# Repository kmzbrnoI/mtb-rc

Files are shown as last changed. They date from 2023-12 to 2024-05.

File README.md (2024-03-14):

MTB-RC – MTBbus RailCom detector
================================

MTB-RC is a RailCom detector sending addresses of a detected mobile decoders
via MTBbus.

## Features

* 8 track sections.
* [MTBbus v4](https://mtb.kmz-brno.cz/) interface.
* Reading DCC addresses of mobile decoders.
* Galvanic separation of MTB & DCC.
* Single STM32F103 main MCU.
* MTB part power input: 8-20 V.
* DCC part powered directly from DCC.
* Several IO & power protections (ESD, overvoltage, switched polarity, ...).
* 4->1 track time multiplexing.
* Opensource & openhardware design.

## PCB

See [README in `pcb` subfolder](pcb/README.md).

## Firmware

See [README in `fw` subfolder](fw/README.md).

## Authors

* Kateřina Hanáková
* [Jan Horáček](mailto:jan.horacek@kmz-brno.cz)

## Licence

See README in subfolders for licenses regarding pcb design and firmware.

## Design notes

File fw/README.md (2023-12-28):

MTB-RC Firmware
===============

This repository contains firmware for main MCU STM32F103 of MTB-RC module written
in C99.

## Compiling

Requirements:
* `arm-none-eabi-gcc`
* STM32CubeF1 MCU Firmware Package v1.8.5
  - Download package
  - Set `STM32_CUBE_PATH_185` environment variable to the location of downloaded package
  - See `Makefile`
* `make`

Howto compile:

```bash
$ make
```

## Flashing

Requirements:
* `st-flash` (via STlink)

MTB-RC module contains programming connector. Use STlink to program the MCU.
```bash
$ make flash_stlink
```

## Debugging

Requirements:
* `openocd`
* `arm-none-eabi-gdb`

Howto debug:

```bash
$ openocd
$ arm-none-eabi-gdb build/mtb-rc.elf
(gdb) target extended-remote :3333
(gdb) b main
```

## License

This application is released under the [Apache License v2.0
](https://www.apache.org/licenses/LICENSE-2.0).

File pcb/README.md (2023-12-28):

MTB-RC PCB
==========

## Design

Schematics & PCB are designed in KiCad 7.

## Production

PCB is prepared to be automatically assembled in [JLCPCB](https://jlcpcb.com/).
SMD parts on **bottom** side should be assembled. Each SMD part has its `LCSC_ITEM`
attribute set.

```bash
$ make fab
```

## License

Content of this directory is provided under [Creative Commons
Attribution-ShareAlike 4.0
License](https://creativecommons.org/licenses/by-sa/4.0/) as openhardware
project. You may download any data, contribute to the project, create PCB
yourself or even sell it yourself.

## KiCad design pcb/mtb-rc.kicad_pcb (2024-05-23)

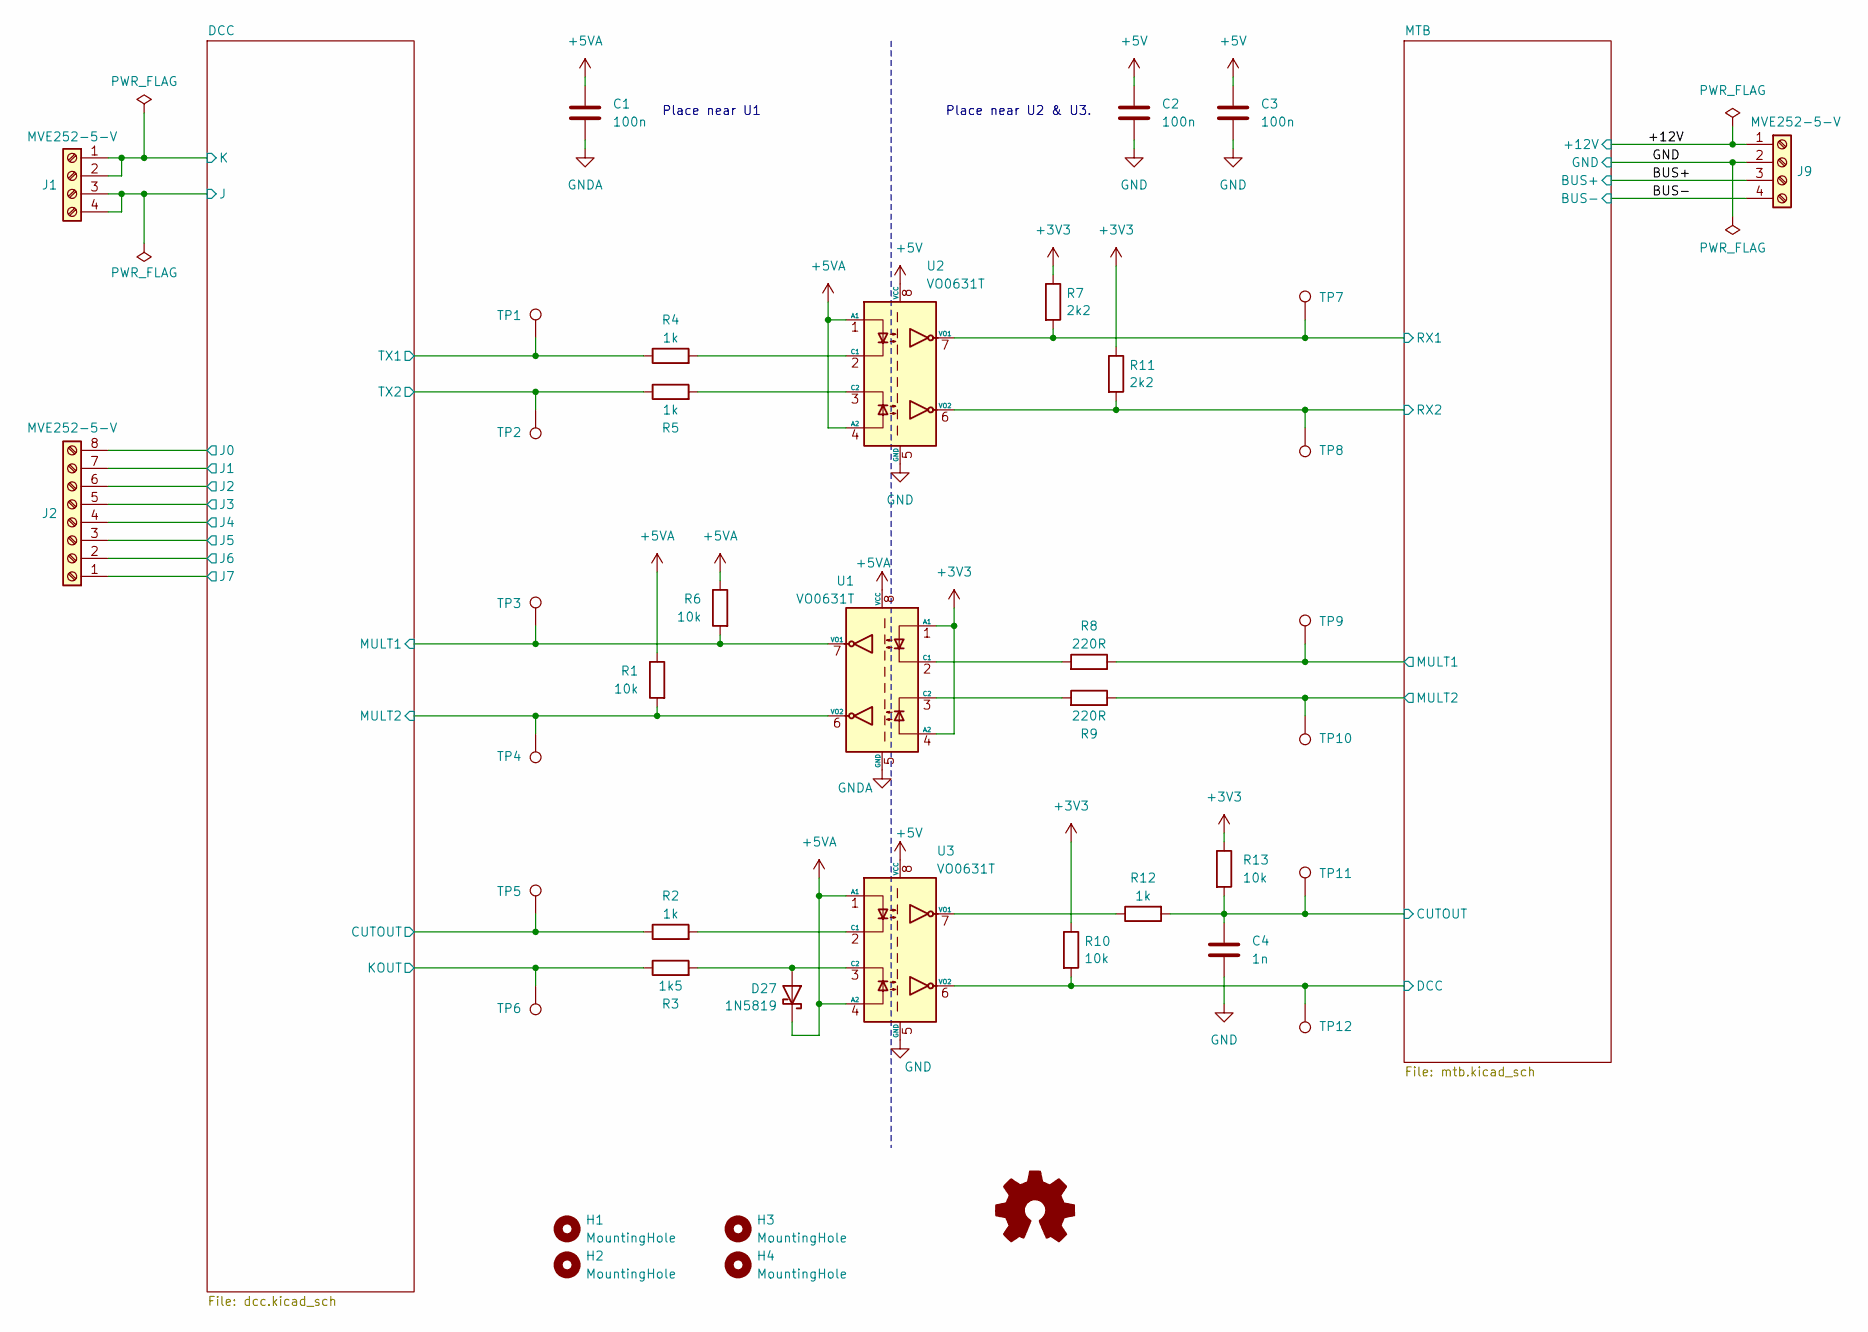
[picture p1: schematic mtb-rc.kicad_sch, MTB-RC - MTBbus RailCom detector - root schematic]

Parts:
C1, C2, C3: 100n; C_0805_2012Metric_Pad1.18x1.45mm_HandSolder
C4: 1n; C_0805_2012Metric_Pad1.18x1.45mm_HandSolder
D27: 1N5819; D_SOD-123
H1, H2, H3, H4: MountingHole; MountingHole_3.2mm_M3_Pad_Via
J1, J9: MVE252-5-V; MVE252-5-V-2x
J2: MVE252-5-V; MVE252-5-V-4x
R1, R6, R10, R13: 10k; R_0805_2012Metric_Pad1.20x1.40mm_HandSolder
R2, R4, R5, R12: 1k; R_0805_2012Metric_Pad1.20x1.40mm_HandSolder
R3: 1k5; R_0805_2012Metric_Pad1.20x1.40mm_HandSolder
R7, R11: 2k2; R_0805_2012Metric_Pad1.20x1.40mm_HandSolder
R8, R9: 220R; R_0805_2012Metric_Pad1.20x1.40mm_HandSolder
TP1, TP2, TP3, TP4, TP5, TP6, TP7, TP8, TP9, TP10, TP11, TP12: PinHeader_1x01_P2.54mm_Vertical
U1, U2, U3: VO0631T; SOIC-8_3.9x4.9mm_P1.27mm

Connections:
+3V3: R7.1, R10.1, R11.1, R13.1, U1.1 (A1), U1.4 (A2); also elsewhere on the board
+5V: C2.1, C3.1, U2.8 (VCC), U3.8 (VCC); also elsewhere on the board
+5VA: C1.1, D27.1 (K), R1.1, R6.1, U1.8 (VCC), U2.1 (A1), U2.4 (A2), U3.1 (A1), U3.4 (A2); also elsewhere on the board
/+12V: J9.1; also elsewhere on the board
/BUS+: J9.3; also elsewhere on the board
/BUS-: J9.4; also elsewhere on the board
/DCC/CUTOUT: R2.1, TP5.1; also elsewhere on the board
/DCC/J: J1.3, J1.4; also elsewhere on the board
/DCC/J0: J2.8; also elsewhere on the board
/DCC/J1: J2.7; also elsewhere on the board
/DCC/J2: J2.6; also elsewhere on the board
/DCC/J3: J2.5; also elsewhere on the board
/DCC/J4: J2.4; also elsewhere on the board
/DCC/J5: J2.3; also elsewhere on the board
/DCC/J6: J2.2; also elsewhere on the board
/DCC/J7: J2.1; also elsewhere on the board
/DCC/MULT1: R6.2, TP3.1, U1.7 (VO1); also elsewhere on the board
/DCC/MULT2: R1.2, TP4.1, U1.6 (VO2); also elsewhere on the board
/DCC/TX1: R4.1, TP1.1; also elsewhere on the board
/DCC/TX2: R5.1, TP2.1; also elsewhere on the board
/MTB/CUTOUT: C4.1, R12.2, R13.2, TP11.1; also elsewhere on the board
/MTB/DCC: R10.2, TP12.1, U3.6 (VO2); also elsewhere on the board
/MTB/MULT1: R8.1, TP9.1; also elsewhere on the board
/MTB/MULT2: R9.1, TP10.1; also elsewhere on the board
/MTB/RX1: R7.2, TP7.1, U2.7 (VO1); also elsewhere on the board
/MTB/RX2: R11.2, TP8.1, U2.6 (VO2); also elsewhere on the board
GND: C2.2, C3.2, C4.2, J9.2, U2.5 (GND), U3.5 (GND); also elsewhere on the board
GNDA: C1.2, U1.5 (GND); also elsewhere on the board
K: J1.1, J1.2; also elsewhere on the board
KOUT: R3.1, TP6.1; also elsewhere on the board
unnamed: D27.2 (A), R3.2, U3.3 (C2)
unnamed: R8.2, U1.2 (C1)
unnamed: R9.2, U1.3 (C2)
unnamed: R4.2, U2.2 (C1)
unnamed: R5.2, U2.3 (C2)
unnamed: R2.2, U3.2 (C1)
unnamed: R12.1, U3.7 (VO1)

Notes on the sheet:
Place near U2 & U3.
Place near U1

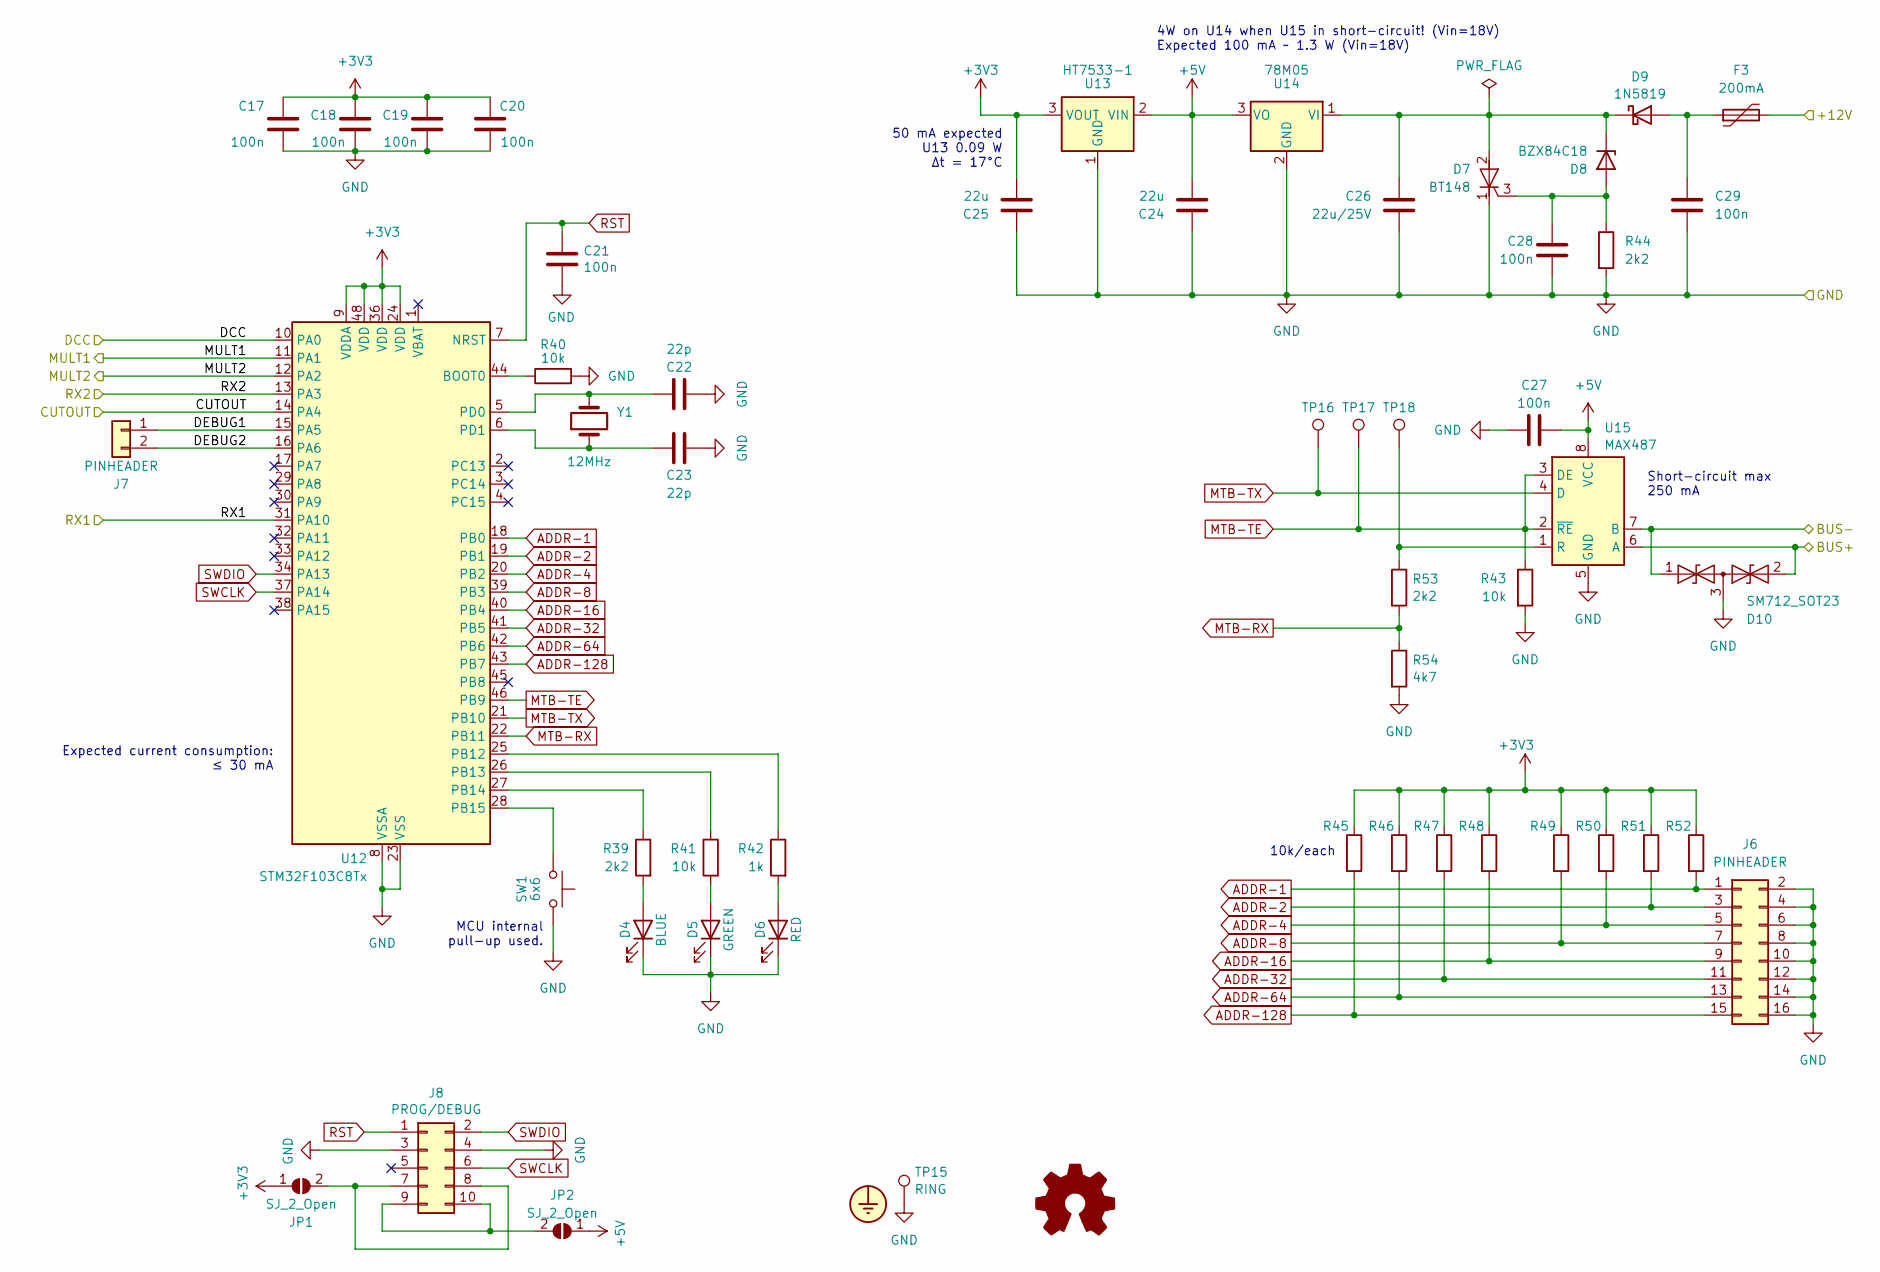
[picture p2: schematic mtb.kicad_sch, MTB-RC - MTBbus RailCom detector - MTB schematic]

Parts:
C17, C18, C19, C20, C27: 100n; C_0805_2012Metric_Pad1.18x1.45mm_HandSolder
C21: 100n; C_0805_2012Metric_Pad1.18x1.45mm_HandSolder; LCSC C49678
C22, C23: 22p; C_0805_2012Metric_Pad1.18x1.45mm_HandSolder
C24, C25: 22u; C_0805_2012Metric_Pad1.18x1.45mm_HandSolder
C26: 22u/25V; C_0805_2012Metric_Pad1.18x1.45mm_HandSolder
C28, C29: 100n; C_0805_2012Metric
D4: BLUE; LED_0805_2012Metric_Pad1.15x1.40mm_HandSolder
D5: GREEN; LED_0805_2012Metric_Pad1.15x1.40mm_HandSolder
D6: RED; LED_0805_2012Metric_Pad1.15x1.40mm_HandSolder
D7: BT148; SOT-223
D8: BZX84C18; SOT-23
D9: 1N5819; D_SOD-123
D10: SM712_SOT23; SOT-23
F3: 200mA; Fuse_1812_4532Metric_Pad1.30x3.40mm_HandSolder
J6: PINHEADER; PinHeader_2x08_P2.54mm_Vertical
J7: PINHEADER; PinHeader_1x02_P2.54mm_Vertical
J8: PROG/DEBUG; PinHeader_2x05_P2.54mm_Vertical; JLCPCB_IGNORE true
JP1, JP2: SJ_2_Open; PinHeader_1x02_P2.54mm_Vertical; JLCPCB_IGNORE true
R39, R44, R53: 2k2; R_0805_2012Metric_Pad1.20x1.40mm_HandSolder
R40, R41, R43, R45, R46, R47, R48, R49, R50, R51, R52: 10k; R_0805_2012Metric_Pad1.20x1.40mm_HandSolder
R42: 1k; R_0805_2012Metric_Pad1.20x1.40mm_HandSolder
R54: 4k7; R_0805_2012Metric_Pad1.20x1.40mm_HandSolder
SW1: 6x6; SW_PUSH_6mm_H4.3mm
TP15: RING; TestPoint_Loop_D1.80mm_Drill1.0mm_Beaded
TP16, TP17, TP18: PAD; PinHeader_1x01_P2.54mm_Vertical
U12: STM32F103C8Tx; LQFP-48_7x7mm_P0.5mm
U13: HT7533-1; SOT-89-3_Handsoldering
U14: 78M05; TO-252-2
U15: MAX487; DIP-8_W7.62mm_LongPads
Y1: 12MHz; Crystal_HC49-U_Vertical

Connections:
+3V3: C17.1, C18.1, C19.1, C20.1, C25.2, JP1.1 (A), R45.1, R46.1, R47.1, R48.1, R49.1, R50.1, R51.1, R52.1, U12.9 (VDDA), U12.24 (VDD), U12.36 (VDD), U12.48 (VDD), U13.3 (VOUT); also elsewhere on the board
+5V: C24.2, C27.1, JP2.1 (A), U13.2 (VIN), U14.3 (VO), U15.8 (VCC); also elsewhere on the board
/+12V: F3.2; also elsewhere on the board
/BUS+: D10.2 (A2), U15.6 (A); also elsewhere on the board
/BUS-: D10.1 (A1), U15.7 (B); also elsewhere on the board
/MTB/CUTOUT: U12.14 (PA4); also elsewhere on the board
/MTB/DCC: U12.10 (PA0); also elsewhere on the board
/MTB/DEBUG1: J7.1, U12.15 (PA5)
/MTB/DEBUG2: J7.2, U12.16 (PA6)
/MTB/MULT1: U12.11 (PA1); also elsewhere on the board
/MTB/MULT2: U12.12 (PA2); also elsewhere on the board
/MTB/RX1: U12.31 (PA10); also elsewhere on the board
/MTB/RX2: U12.13 (PA3); also elsewhere on the board
ADDR-1: J6.1, R52.2, U12.18 (PB0)
ADDR-2: J6.3, R51.2, U12.19 (PB1)
ADDR-4: J6.5, R50.2, U12.20 (PB2)
ADDR-8: J6.7, R49.2, U12.39 (PB3)
ADDR-16: J6.9, R48.2, U12.40 (PB4)
ADDR-32: J6.11, R47.2, U12.41 (PB5)
ADDR-64: J6.13, R46.2, U12.42 (PB6)
ADDR-128: J6.15, R45.2, U12.43 (PB7)
GND: C17.2, C18.2, C19.2, C20.2, C21.1, C22.2, C23.2, C24.1, C25.1, C26.2, C27.2, C28.2, C29.2, D4.1 (K), D5.1 (K), D6.1 (K), D7.1 (K), D10.3 (common), J6.2, J6.4, J6.6, J6.8, J6.10, J6.12, J6.14, J6.16, J8.3, J8.4, R40.2, R43.2, R44.2, R54.2, SW1.1, TP15.1, U12.8 (VSSA), U12.23 (VSS), U12.35 (VSS), U12.47 (VSS), U13.1 (GND), U14.2 (GND), U15.5 (GND); also elsewhere on the board
MTB-RX: R53.2, R54.1, U12.22 (PB11)
MTB-TE: R43.1, TP17.1, U12.46 (PB9), U15.2 (~RE), U15.3 (DE)
MTB-TX: TP16.1, U12.21 (PB10), U15.4 (D)
unnamed: D4.2 (A), R39.2
unnamed: D5.2 (A), R41.2
unnamed: D6.2 (A), R42.2
unnamed: C26.1, D7.2 (A), D8.3 (K), D9.1 (K), U14.1 (VI)
unnamed: C28.1, D7.3 (G), D8.1 (A), R44.1
unnamed: C29.1, D9.2 (A), F3.1
unnamed: J8.7, J8.8, JP1.2 (B)
unnamed: J8.9, J8.10, JP2.2 (B)
unnamed: R40.1, U12.44 (BOOT0)
unnamed: R42.1, U12.25 (PB12)
unnamed: R41.1, U12.26 (PB13)
unnamed: R39.1, U12.27 (PB14)
unnamed: SW1.2, U12.28 (PB15)
unnamed: C22.1, U12.5 (PD0), Y1.2
unnamed: C23.1, U12.6 (PD1), Y1.1
unnamed: R53.1, TP18.1, U15.1 (R)
RST: C21.2, J8.1, U12.7 (NRST)
SWCLK: J8.6, U12.37 (PA14)
SWDIO: J8.2, U12.34 (PA13)

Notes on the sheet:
4W on U14 when U15 in short-circuit! (Vin=18V) Expected 100 mA ~ 1.3 W (Vin=18V)
Expected current consumption: ≤ 30 mA
50 mA expected U13 0.09 W Δt = 17°C
10k/each
Short-circuit max 250 mA
MCU internal pull-up used.

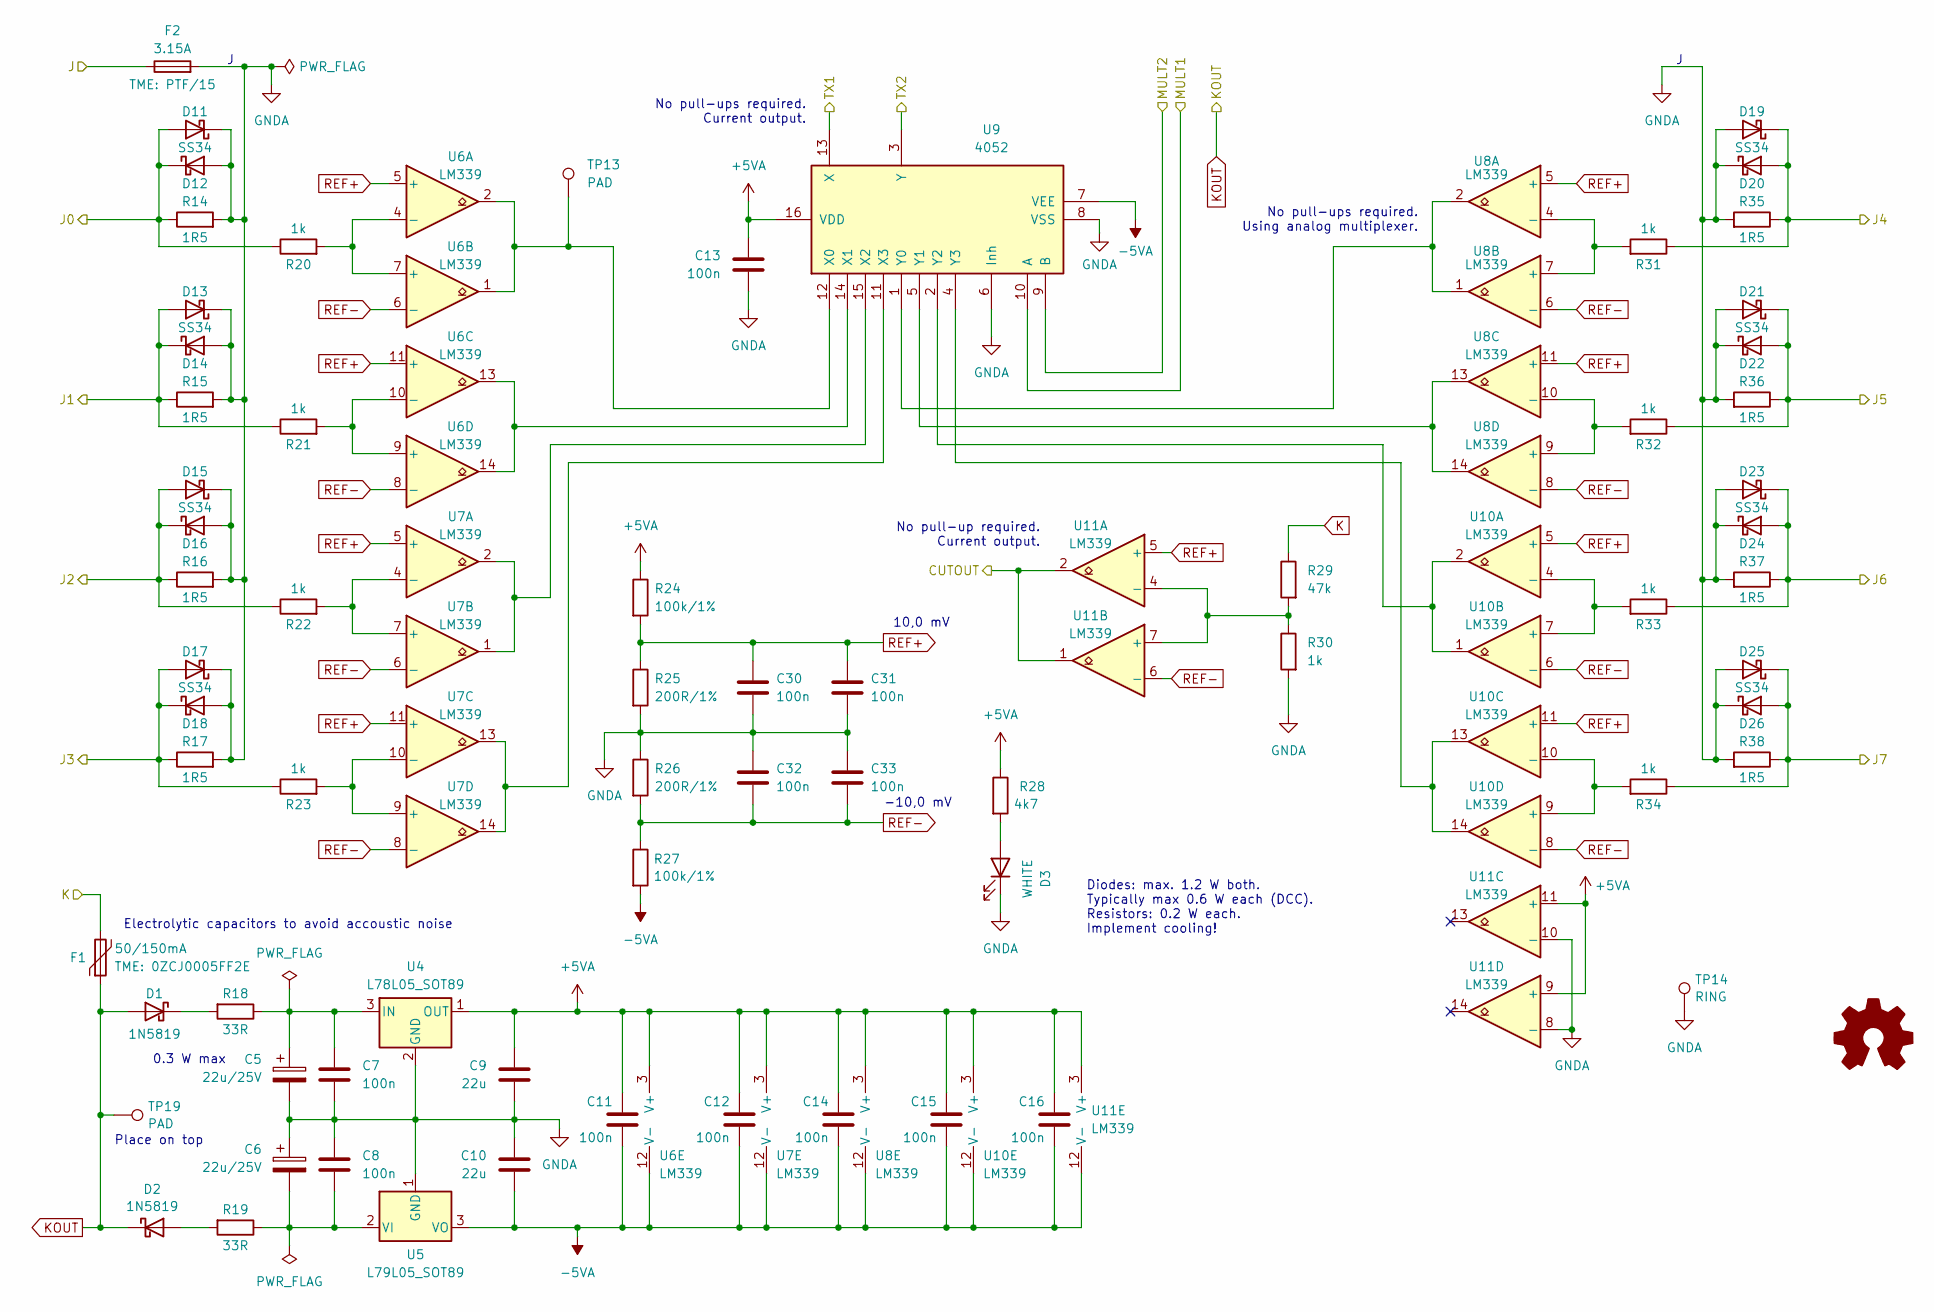
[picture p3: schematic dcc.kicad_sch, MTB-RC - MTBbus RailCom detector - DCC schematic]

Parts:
C5, C6: 22u/25V; CP_Radial_D5.0mm_P2.00mm
C7, C8, C30, C32: 100n; C_0805_2012Metric_Pad1.18x1.45mm_HandSolder
C9, C10: 22u; C_0805_2012Metric_Pad1.18x1.45mm_HandSolder
C11, C12, C13, C14, C15, C16, C31, C33: 100n; C_0805_2012Metric
D1, D2: 1N5819; D_SOD-123
D3: WHITE; LED_0805_2012Metric_Pad1.15x1.40mm_HandSolder
D11, D12, D13, D14, D15, D16, D17, D18, D19, D20, D21, D22, D23, D24, D25, D26: SS34; D_SMA_Handsoldering
F1: 50/150mA; Fuse_1206_3216Metric_Pad1.42x1.75mm_HandSolder
F2: 3.15A; Fuseholder_Cylinder-5x20mm_Stelvio-Kontek_PTF78_Horizontal_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
R14, R15, R16, R17, R35, R36, R37, R38: 1R5; R_2512_6332Metric_Pad1.40x3.35mm_HandSolder
R18, R19: 33R; R_2512_6332Metric_Pad1.40x3.35mm_HandSolder
R20, R21, R22, R23, R30, R31, R32, R33, R34: 1k; R_0805_2012Metric
R24, R27: 100k/1%; R_0805_2012Metric_Pad1.20x1.40mm_HandSolder
R25, R26: 200R/1%; R_0805_2012Metric_Pad1.20x1.40mm_HandSolder
R28: 4k7; R_0805_2012Metric_Pad1.20x1.40mm_HandSolder
R29: 47k; R_0805_2012Metric
TP13, TP19: PAD; TestPoint_Pad_D2.0mm
TP14: RING; TestPoint_Loop_D1.80mm_Drill1.0mm_Beaded
U4: L78L05_SOT89; SOT-89-3
U5: L79L05_SOT89; SOT-89-3
U6, U7, U8, U10, U11: LM339; SO-14_3.9x8.65mm_P1.27mm
U9: 4052; SO-16_3.9x9.9mm_P1.27mm

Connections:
+5VA: C9.1, C11.1, C12.1, C13.1, C14.1, C15.1, C16.1, R24.1, R28.1, U4.1 (OUT), U6.3 (V+), U7.3 (V+), U8.3 (V+), U9.16 (VDD), U10.3 (V+), U11.3 (V+), U11.9 (+), U11.11 (+); also elsewhere on the board
-5VA: C10.2, C11.2, C12.2, C14.2, C15.2, C16.2, R27.2, U5.3 (VO), U6.12 (V-), U7.12 (V-), U8.12 (V-), U9.7 (VEE), U10.12 (V-), U11.12 (V-)
/DCC/CUTOUT: U11.1, U11.2; also elsewhere on the board
/DCC/J: F2.1; also elsewhere on the board
/DCC/J0: D11.2 (A), D12.1 (K), R14.1, R20.1; also elsewhere on the board
/DCC/J1: D13.2 (A), D14.1 (K), R15.1, R21.1; also elsewhere on the board
/DCC/J2: D15.2 (A), D16.1 (K), R16.1, R22.1; also elsewhere on the board
/DCC/J3: D17.2 (A), D18.1 (K), R17.1, R23.1; also elsewhere on the board
/DCC/J4: D19.1 (K), D20.2 (A), R31.1, R35.1; also elsewhere on the board
/DCC/J5: D21.1 (K), D22.2 (A), R32.1, R36.1; also elsewhere on the board
/DCC/J6: D23.1 (K), D24.2 (A), R33.1, R37.1; also elsewhere on the board
/DCC/J7: D25.1 (K), D26.2 (A), R34.1, R38.1; also elsewhere on the board
/DCC/MULT1: U9.10 (A); also elsewhere on the board
/DCC/MULT2: U9.9 (B); also elsewhere on the board
/DCC/TX1: U9.13 (X); also elsewhere on the board
/DCC/TX2: U9.3 (Y); also elsewhere on the board
GNDA: C5.2, C6.1, C7.2, C8.1, C9.2, C10.1, C13.2, C30.2, C31.2, C32.1, C33.1, D3.1 (K), D11.1 (K), D12.2 (A), D13.1 (K), D14.2 (A), D15.1 (K), D16.2 (A), D17.1 (K), D18.2 (A), D19.2 (A), D20.1 (K), D21.2 (A), D22.1 (K), D23.2 (A), D24.1 (K), D25.2 (A), D26.1 (K), F2.2, R14.2, R15.2, R16.2, R17.2, R25.2, R26.1, R30.2, R35.2, R36.2, R37.2, R38.2, TP14.1, U4.2 (GND), U5.1 (GND), U9.6 (Inh), U9.8 (VSS), U11.8 (-), U11.10 (-); also elsewhere on the board
K: F1.2, R29.1; also elsewhere on the board
KOUT: D1.2 (A), D2.1 (K), F1.1, TP19.1; also elsewhere on the board
unnamed: D1.1 (K), R18.2
unnamed: D2.2 (A), R19.2
unnamed: D3.2 (A), R28.2
unnamed: C5.1, C7.1, R18.1, U4.3 (IN)
unnamed: C6.2, C8.2, R19.1, U5.2 (VI)
unnamed: R20.2, U6.4 (-), U6.7 (+)
unnamed: R21.2, U6.9 (+), U6.10 (-)
unnamed: R22.2, U7.4 (-), U7.7 (+)
unnamed: R23.2, U7.9 (+), U7.10 (-)
unnamed: R31.2, U8.4 (-), U8.7 (+)
unnamed: R32.2, U8.9 (+), U8.10 (-)
unnamed: TP13.1, U6.1, U6.2, U9.12 (X0)
unnamed: U6.13, U6.14, U9.14 (X1)
unnamed: U7.1, U7.2, U9.15 (X2)
unnamed: U7.13, U7.14, U9.11 (X3)
unnamed: U8.1, U8.2, U9.1 (Y0)
unnamed: U8.13, U8.14, U9.5 (Y1)
unnamed: U9.2 (Y2), U10.1, U10.2
unnamed: U9.4 (Y3), U10.13, U10.14
unnamed: R33.2, U10.4 (-), U10.7 (+)
unnamed: R34.2, U10.9 (+), U10.10 (-)
unnamed: R29.2, R30.1, U11.4 (-), U11.7 (+)
REF+: C30.1, C31.1, R24.2, R25.1, U6.5 (+), U6.11 (+), U7.5 (+), U7.11 (+), U8.5 (+), U8.11 (+), U10.5 (+), U10.11 (+), U11.5 (+)
REF-: C32.2, C33.2, R26.2, R27.1, U6.6 (-), U6.8 (-), U7.6 (-), U7.8 (-), U8.6 (-), U8.8 (-), U10.6 (-), U10.8 (-), U11.6 (-)

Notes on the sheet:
10,0 mV
No pull-ups required. Current output.
Diodes: max. 1.2 W both. Typically max 0.6 W each (DCC). Resistors: 0.2 W each. Implement cooling!
No pull-ups required. Using analog multiplexer.
Place on top
Electrolytic capacitors to avoid accoustic noise
0.3 W max
No pull-up required. Current output.
-10,0 mV

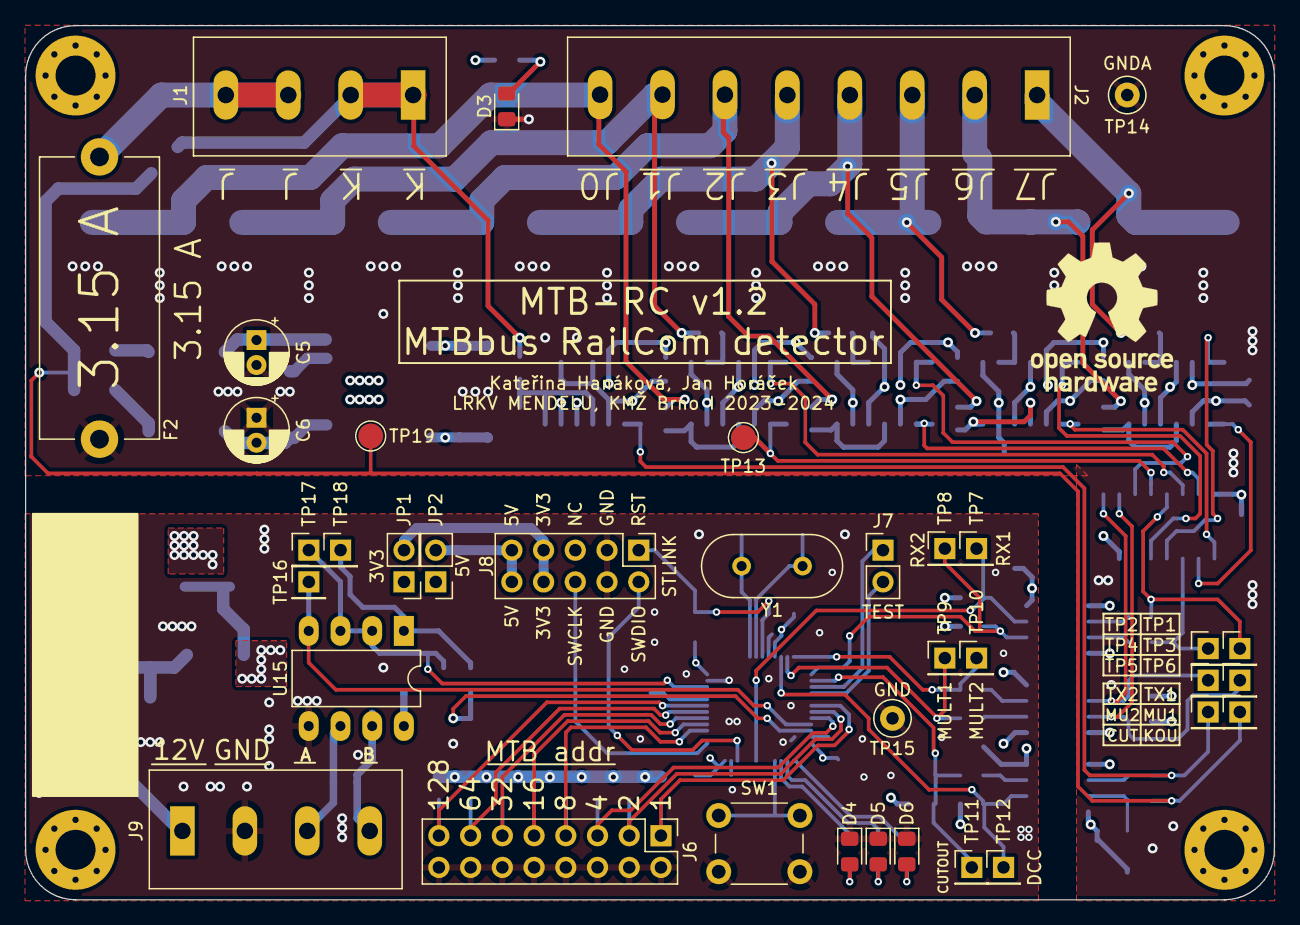
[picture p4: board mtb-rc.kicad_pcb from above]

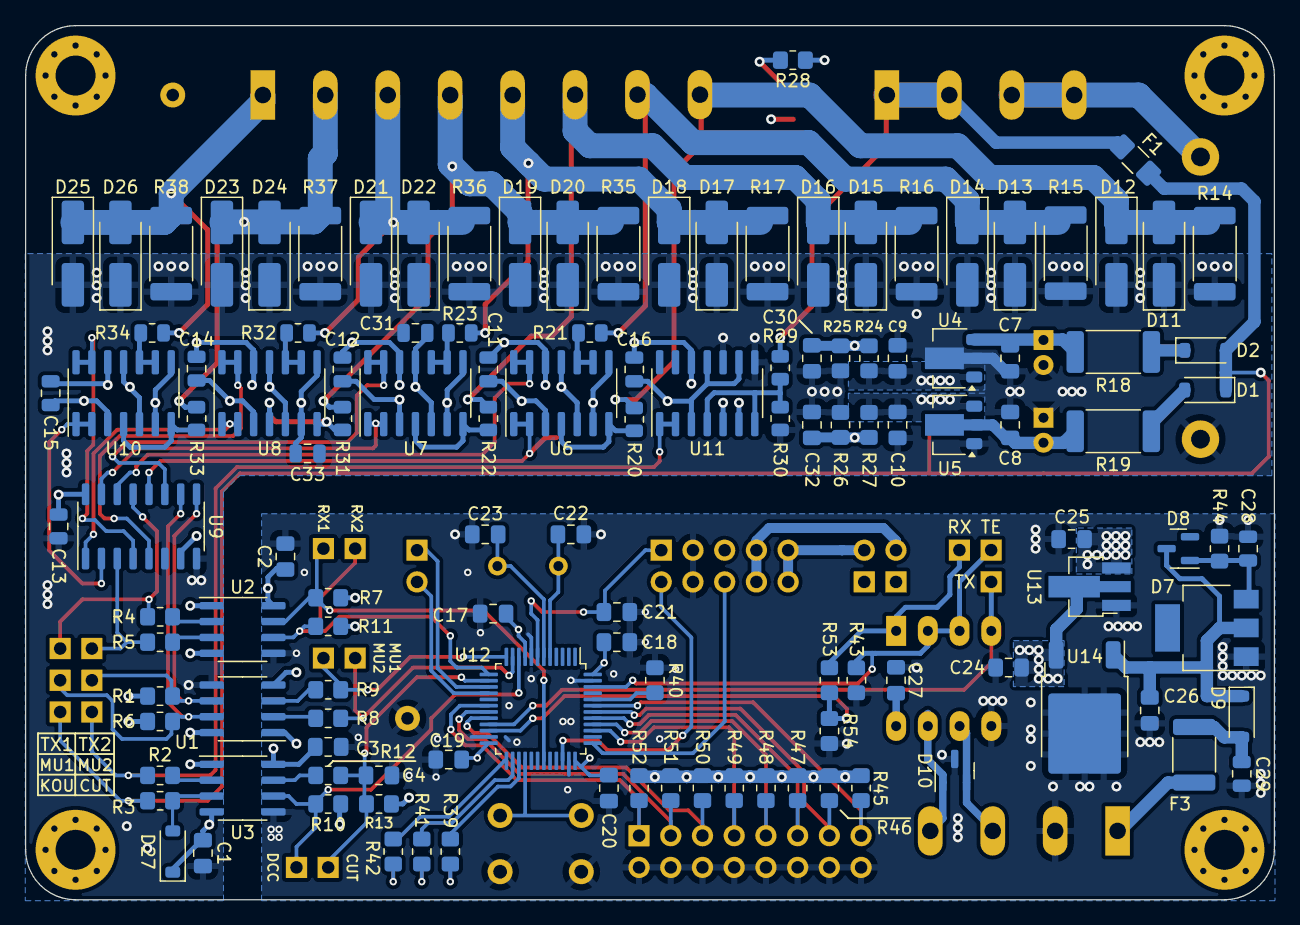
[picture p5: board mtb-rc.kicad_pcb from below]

Board: 4 copper layers, 100.0 x 70.0 mm, 165 parts (124 on the bottom side), 94 nets.

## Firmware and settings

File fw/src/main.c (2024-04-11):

#include <stdbool.h>
#include <string.h>
#include "dwt_delay.h"
#include "assert.h"
#include "main.h"
#include "gpio.h"
#include "mtbbus.h"
#include "railcom_ll.h"
#include "railcom_mw.h"
#include "railcom_addrs.h"
#include "config.h"
#include "diag.h"
#include "inputs.h"
#include "dcc_ll.h"
#include "dcc_mw.h"
#include "common.h"

/* Private variables ---------------------------------------------------------*/

TIM_HandleTypeDef htim3; // general-purpose @ 500 us

#define LED_GR_ON 5
#define LED_GR_OFF 2
uint8_t led_gr_counter = 0;

#define LED_RED_OK_ON 40
#define LED_RED_OK_OFF 20
#define LED_RED_ERR_ON 100
#define LED_RED_ERR_OFF 50
uint8_t led_red_counter = 0;

bool beacon = false;

#define LED_BLUE_BEACON_ON 100
#define LED_BLUE_BEACON_OFF 50
uint8_t led_blue_counter = 0;

volatile bool btn_debounce_to_update = false;

#define MTBBUS_TIMEOUT_MAX 100 // 1 s
volatile uint8_t mtbbus_timeout = MTBBUS_TIMEOUT_MAX; // increment each 10 ms

#define BTN_PRESS_1S 100
volatile uint8_t btn_press_time = 0;

volatile bool mtbbus_auto_speed_in_progress = false;
volatile uint8_t mtbbus_auto_speed_timer = 0;
volatile MtbBusSpeed mtbbus_auto_speed_last;
#define MTBBUS_AUTO_SPEED_TIMEOUT 20 // 200 ms

volatile bool elapsed_10ms = false;
volatile bool elapsed_100ms = false;

/* Private function prototypes -----------------------------------------------*/

static void init(void);
static void init_clock(void);
static void init_tim3(void);
static void timer_10ms(void);

void mtbbus_received(bool broadcast, uint8_t command_code, uint8_t *data, uint8_t data_len); // intentionally not static
static void mtbbus_send_ack(void);
static void mtbbus_send_inputs(uint8_t message_code);
static void mtbbus_send_error(uint8_t code);
static void mtbbus_update_polarity(void);
static inline bool mtbbus_addressed(void);
static void mtbbus_send_diag_value(uint8_t i);

static void autodetect_mtbbus_speed(void);
static void autodetect_mtbbus_speed_stop(void);
static void mtbbus_auto_speed_next(void);
static void mtbbus_auto_speed_received(void);

static void leds_update(void);
static void led_red_ok(void);

static void btn_short_press(void);
static void btn_long_press(void);

/* Implementation ------------------------------------------------------------*/

int main(void) {
    init();

    while (true) {
        mtbbus_update();
        rcmw_update();
        dcc_ll_update();
        dcc_mw_update();

        if (btn_debounce_to_update) {
            btn_debounce_to_update = false;
            btn_debounce_update();
        }

        if (config_write) {
            config_write = false;
            config_save();
        }

        if (btn_press_time == BTN_PRESS_1S) {
            btn_press_time = 0xFF;
            btn_long_press();
        }

        if ((mtbbus_auto_speed_in_progress) && (mtbbus_auto_speed_timer == MTBBUS_AUTO_SPEED_TIMEOUT))
            mtbbus_auto_speed_next();

        if (elapsed_10ms) {
            elapsed_10ms = false;
            leds_update();
        }

        if (elapsed_100ms) {
            elapsed_100ms = false;
            rca_update_100ms();
            rcmw_update_100ms();
            diag_update();
            rcmw_mux_to_change(); // change RailCom multiplexing each 100 ms
        }
    }
}

/* Init ----------------------------------------------------------------------*/

void init(void) {
    bool success = (HAL_Init() == HAL_OK);
    assert_param(success);

    init_clock();
    DWT_Init();

    __HAL_RCC_AFIO_CLK_ENABLE();
    __HAL_RCC_PWR_CLK_ENABLE();
    __HAL_AFIO_REMAP_SWJ_NOJTAG();

    gpio_init();

    gpio_pin_write(pin_led_red, true);
    gpio_pin_write(pin_led_green, true);
    gpio_pin_write(pin_led_blue, true);

    init_tim3();

    config_load();

    uint8_t _mtbbus_addr = gpio_mtbbus_addr();
    error_flags.bits.addr_zero = (_mtbbus_addr == 0);
    mtbbus_init(_mtbbus_addr, config_mtbbus_speed);
    mtbbus_on_receive = mtbbus_received;
    mtbbus_update_polarity();

    railcom_ll_init();
    rcmw_init();
    rca_init();
    dcc_ll_init();
    dcc_mw_init();

    HAL_Delay(200);

    gpio_pin_write(pin_led_red, false);
    gpio_pin_write(pin_led_green, false);
    gpio_pin_write(pin_led_blue, false);
}

void init_clock(void) {
    RCC_OscInitTypeDef RCC_OscInitStruct = {0};
    RCC_ClkInitTypeDef RCC_ClkInitStruct = {0};

    /** Initializes the RCC Oscillators according to the specified parameters
    * in the RCC_OscInitTypeDef structure.
    */
    RCC_OscInitStruct.OscillatorType = RCC_OSCILLATORTYPE_HSE;
    RCC_OscInitStruct.HSEState = RCC_HSE_ON;
    RCC_OscInitStruct.HSEPredivValue = RCC_HSE_PREDIV_DIV1;
    RCC_OscInitStruct.HSIState = RCC_HSI_ON;
    RCC_OscInitStruct.PLL.PLLState = RCC_PLL_ON;
    RCC_OscInitStruct.PLL.PLLSource = RCC_PLLSOURCE_HSE;
    RCC_OscInitStruct.PLL.PLLMUL = RCC_PLL_MUL4;
    assert_param(HAL_RCC_OscConfig(&RCC_OscInitStruct) == HAL_OK);

    /** Initializes the CPU, AHB and APB buses clocks
    */
    RCC_ClkInitStruct.ClockType = RCC_CLOCKTYPE_HCLK|RCC_CLOCKTYPE_SYSCLK
                              |RCC_CLOCKTYPE_PCLK1|RCC_CLOCKTYPE_PCLK2;
    RCC_ClkInitStruct.SYSCLKSource = RCC_SYSCLKSOURCE_PLLCLK;
    RCC_ClkInitStruct.AHBCLKDivider = RCC_SYSCLK_DIV1;
    RCC_ClkInitStruct.APB1CLKDivider = RCC_HCLK_DIV2;
    RCC_ClkInitStruct.APB2CLKDivider = RCC_HCLK_DIV1;

    assert_param(HAL_RCC_ClockConfig(&RCC_ClkInitStruct, FLASH_LATENCY_0) == HAL_OK);

    /** Enables the Clock Security System
    */
    HAL_RCC_EnableCSS();
}

void init_tim3(void) {
    // General-purpose TIM3 @ 500 us
    __HAL_RCC_TIM3_CLK_ENABLE();

    htim3.Instance = TIM3;
    htim3.Init.Prescaler = 100;
    htim3.Init.CounterMode = TIM_COUNTERMODE_UP;
    htim3.Init.Period = 240;
    htim3.Init.ClockDivision = TIM_CLOCKDIVISION_DIV1;
    htim3.Init.AutoReloadPreload = TIM_AUTORELOAD_PRELOAD_DISABLE;
    assert_param(HAL_TIM_Base_Init(&htim3) == HAL_OK);

    /* TIM3 interrupt Init */
    HAL_NVIC_SetPriority(TIM3_IRQn, 0, 0);
    HAL_NVIC_EnableIRQ(TIM3_IRQn);

    HAL_TIM_Base_Start_IT(&htim3);
}

/* System stuff --------------------------------------------------------------*/

// Non-maskable interrupt
void NMI_Handler(void) {
    HAL_RCC_NMI_IRQHandler();
    while (1) {
    }
}

void HardFault_Handler(void) {
    while (1) {
    }
}

void MemManage_Handler(void) {
    while (1) {
    }
}

void BusFault_Handler(void) {
    while (1) {
    }
}

void UsageFault_Handler(void) {
    while (1) {
    }
}

// System service call via SWI instruction
void SVC_Handler(void) {
}

// Debug monitor
void DebugMon_Handler(void) {
}

// Pendable request for system service
void PendSV_Handler(void) {
}

// System tick timer
void SysTick_Handler(void) {
    HAL_IncTick();
}

#ifdef  USE_FULL_ASSERT
/**
  * @brief  Reports the name of the source file and the source line number
  *         where the assert_param error has occurred.
  * @param  file: pointer to the source file name
  * @param  line: assert_param error line source number
  * @retval None
  */
void assert_failed(uint8_t *file, uint32_t line) {
    __disable_irq();

    gpio_pin_write(pin_led_green, false);
    gpio_pin_write(pin_led_blue, false);
    while (1) {
        gpio_pin_write(pin_led_red, true);
        for (size_t i = 0; i < (1U << 20); i++) { __asm__("NOP"); }
        gpio_pin_write(pin_led_red, false);
        for (size_t i = 0; i < (1U << 20); i++) { __asm__("NOP"); }
    }
}
#endif /* USE_FULL_ASSERT */

/* "Application" code --------------------------------------------------------*/

// General-purpose TIM3 @ 500 us
void TIM3_IRQHandler(void) {
    HAL_TIM_IRQHandler(&htim3);
    btn_debounce_to_update = true;
    if (dcc_time_since_address < DCC_TIME_SINCE_ADDRESS_MAX)
        dcc_time_since_address++;

    static unsigned tim_10ms = 0;
    tim_10ms++;
    if (tim_10ms >= 20) {
        tim_10ms = 0;
        timer_10ms();
    }
}

void timer_10ms(void) {
    elapsed_10ms = true;

    if (mtbbus_timeout < MTBBUS_TIMEOUT_MAX)
        mtbbus_timeout++;

    if ((btn_pressed) && (btn_press_time < BTN_PRESS_1S))
        btn_press_time++;

    if ((mtbbus_auto_speed_in_progress) && (mtbbus_auto_speed_timer < MTBBUS_AUTO_SPEED_TIMEOUT))
        mtbbus_auto_speed_timer++;

    static size_t counter_100ms = 0;
    counter_100ms++;
    if (counter_100ms >= 10) { // 100 ms
        elapsed_100ms = true;
        counter_100ms = 0;
    }
}

/* MTBbus --------------------------------------------------------------------*/

void mtbbus_received(bool broadcast, uint8_t command_code, uint8_t *data, uint8_t data_len) {
    //if (!initialized)
    //    return;

    error_flags.bits.bad_mtbbus_polarity = false;
    if (led_gr_counter == 0) {
        gpio_pin_write(pin_led_green, true);
        led_gr_counter = LED_GR_ON;
    }
    DWT_Delay(2);

    mtbbus_timeout = 0;
    if (mtbbus_auto_speed_in_progress)
        mtbbus_auto_speed_received();

    switch (command_code) {

    case MTBBUS_CMD_MOSI_MODULE_INQUIRY:
        if ((!broadcast) && (data_len >= 1)) {
            static bool last_input_changed = false;
            static bool first_scan = true;
            bool last_ok = data[0] & 0x01;

            if ((rc_tracks_changed) || (first_scan) || (last_input_changed && !last_ok)) {
                last_input_changed = true;
                first_scan = false;
                rc_tracks_changed = false;
                mtbbus_send_inputs(MTBBUS_CMD_MISO_INPUT_CHANGED);
            } else {
                last_input_changed = false;
                mtbbus_send_ack();
            }

        } else { goto INVALID_MSG; }
        break;

    case MTBBUS_CMD_MOSI_INFO_REQ:
        if (!broadcast) {
            uint16_t bootloader_ver = config_bootloader_version();
            mtbbus_output_buf[0] = 9;
            mtbbus_output_buf[1] = MTBBUS_CMD_MISO_MODULE_INFO;
            mtbbus_output_buf[2] = CONFIG_MODULE_TYPE;
            mtbbus_output_buf[3] = (mtbbus_warn_flags.all > 0) << 2;
            mtbbus_output_buf[4] = CONFIG_FW_MAJOR;
            mtbbus_output_buf[5] = CONFIG_FW_MINOR;
            mtbbus_output_buf[6] = CONFIG_PROTO_MAJOR;
            mtbbus_output_buf[7] = CONFIG_PROTO_MINOR;
            mtbbus_output_buf[8] = bootloader_ver >> 8;
            mtbbus_output_buf[9] = bootloader_ver & 0xFF;
            mtbbus_send_buf_autolen();
        } else { goto INVALID_MSG; }
        break;

    case MTBBUS_CMD_MOSI_SET_CONFIG:
        if ((data_len == 0) && (!broadcast)) { // no configuration for MTB-RC module
            mtbbus_send_ack();
        } else { goto INVALID_MSG; }
        break;

    case MTBBUS_CMD_MOSI_GET_CONFIG:
        if (!broadcast) {
            mtbbus_output_buf[0] = 1;
            mtbbus_output_buf[1] = MTBBUS_CMD_MISO_MODULE_CONFIG;
            mtbbus_send_buf_autolen();
        } else { goto INVALID_MSG; }
        break;

    case MTBBUS_CMD_MOSI_BEACON:
        if (data_len >= 1) {
            beacon = data[0];
            if (!broadcast)
                mtbbus_send_ack();
        } else { goto INVALID_MSG; }
        break;

    case MTBBUS_CMD_MOSI_GET_INPUT:
        if (!broadcast) {
            mtbbus_send_inputs(MTBBUS_CMD_MISO_INPUT_STATE);
        } else { goto INVALID_MSG; }
        break;

    case MTBBUS_CMD_MOSI_RESET_OUTPUTS:
        if (!broadcast)
            mtbbus_send_ack();
        break;

    case MTBBUS_CMD_MOSI_CHANGE_ADDR:
        if ((data_len >= 1) && (!broadcast)) {
            mtbbus_send_error(MTBBUS_ERROR_UNSUPPORTED_COMMAND);
        } else { goto INVALID_MSG; }
        break;

    case MTBBUS_CMD_MOSI_CHANGE_SPEED:
        if (data_len >= 1) {
            config_mtbbus_speed = data[0];
            config_write = true;
            mtbbus_set_speed(data[0]);

            if (!broadcast)
                mtbbus_send_ack();
        } else { goto INVALID_MSG; }
        break;

    case MTBBUS_CMD_MOSI_FWUPGD_REQUEST:
        if ((data_len >= 1) && (!broadcast)) {
            config_boot_fwupgd();
            mtbbus_on_sent = &NVIC_SystemReset;
            mtbbus_send_ack();
        } else { goto INVALID_MSG; }
        break;

    case MTBBUS_CMD_MOSI_REBOOT:
        if (broadcast) {
            NVIC_SystemReset();
        } else {
            mtbbus_on_sent = &NVIC_SystemReset;
            mtbbus_send_ack();
        }
        break;

    case MTBBUS_CMD_MOSI_DIAG_VALUE_REQ:
        if (data_len >= 1) {
            mtbbus_send_diag_value(data[0]);
        } else { goto INVALID_MSG; }
        break;

INVALID_MSG:
    default:
        if (!broadcast)
            mtbbus_send_error(MTBBUS_ERROR_UNKNOWN_COMMAND);

    };
}

// Warning: functions below don't check mtbbus_can_fill_output_buf(), bacause
// they should be called ONLY from mtbbus_received event (as MTBbus is
// request-response based bus).

void mtbbus_send_ack(void) {
    mtbbus_output_buf[0] = 1;
    mtbbus_output_buf[1] = MTBBUS_CMD_MISO_ACK;
    mtbbus_send_buf_autolen();
}

void mtbbus_send_inputs(uint8_t message_code) {
    mtbbus_output_buf[1] = message_code;

    size_t i = 2;
    for (size_t track = 0; track < RC_TRACKS_COUNT; track++) {
        for (size_t addri = 0; addri < rc_tracks[track].count; addri++) {
            if (i < MTBBUS_MAX_INPUT_BYTES) {
                const uint16_t addr = rc_tracks[track].addrs[addri].addr;
                mtbbus_output_buf[i++] = ((addr >> 8) & 0x1F) | (track << 5);
                mtbbus_output_buf[i++] = addr & 0xFF;
            }
        }
    }
    mtbbus_output_buf[0] = i-1; // length
    mtbbus_send_buf_autolen();
}

void mtbbus_send_error(uint8_t code) {
    mtbbus_output_buf[0] = 2;
    mtbbus_output_buf[1] = MTBBUS_CMD_MISO_ERROR;
    mtbbus_output_buf[2] = code;
    mtbbus_send_buf_autolen();
}

void mtbbus_update_polarity(void) {
    error_flags.bits.bad_mtbbus_polarity = !gpio_pin_read(pin_mtbbus_rx);
}

void mtbbus_send_diag_value(uint8_t i) {
    mtbbus_output_buf[1] = MTBBUS_CMD_MISO_DIAG_VALUE;
    mtbbus_output_buf[2] = i;

    // Most of DVs are 32bit
    mtbbus_output_buf[0] = 2+4;

    if ((i >= dvRCMWFirst) && (i <= dvRCMWLast)) {
        // A little bit of pointer-arithmetic magic...
        memcpy(&mtbbus_output_buf[3], (uint32_t*)(&rc_mw_diag)+(i-dvRCMWFirst), sizeof(uint32_t));
        mtbbus_send_buf_autolen();
        return;
    }

    if ((i >= dvRCMWTrackFirst) && (i <= dvRCMWTrackLast)) {
        // A little bit of pointer-arithmetic magic...
        unsigned track = (i-dvRCMWTrackFirst) / 10;
        unsigned member_i = (i-dvRCMWTrackFirst) % 10;
        if (member_i < dviRCMWCount) {
            memcpy(&mtbbus_output_buf[3], (uint32_t*)(&rc_mw_track_diag[track])+member_i, sizeof(uint32_t));
            mtbbus_send_buf_autolen();
            return;
        }
    }

    switch (i) {
    case dvVersion:
        mtbbus_output_buf[0] = 2+1;
        mtbbus_output_buf[3] = 0x10;
        break;

    case dvState:
        mtbbus_output_buf[0] = 2+1;
        mtbbus_output_buf[3] = (mtbbus_warn_flags.all > 0) << 1;
        break;

    case dvUptime:
        MEMCPY_FROM_VAR(&mtbbus_output_buf[3], uptime_seconds);
        break;

    case dvWarnings:
        mtbbus_warn_flags_old = mtbbus_warn_flags;
        mtbbus_output_buf[0] = 2+1;
        mtbbus_output_buf[3] = mtbbus_warn_flags.all;
        break;

    case dvMtbBusReceived:
        MEMCPY_FROM_VAR(&mtbbus_output_buf[3], mtbbus_diag.received);
        break;

    case dvMtbBusBadCrc:
        MEMCPY_FROM_VAR(&mtbbus_output_buf[3], mtbbus_diag.bad_crc);
        break;

    case dvMtbBusSent:
        MEMCPY_FROM_VAR(&mtbbus_output_buf[3], mtbbus_diag.sent);
        break;

    case dvRCLLCutoutsStarted:
        MEMCPY_FROM_VAR(&mtbbus_output_buf[3], rc_ll_diag.cutouts_started);
        break;

    case dvRCLLCutoutsFinished:
        MEMCPY_FROM_VAR(&mtbbus_output_buf[3], rc_ll_diag.cutouts_finished);
        break;

    case dvRCLLCutoutsTimeout:
        MEMCPY_FROM_VAR(&mtbbus_output_buf[3], rc_ll_diag.cutouts_timeout);
        break;

    case dvRCLLCutoutsDataCh1:
        MEMCPY_FROM_VAR(&mtbbus_output_buf[3], rc_ll_diag.cutouts_data_ch1);
        break;

    case dvRCLLCutoutsDataCh2:
        MEMCPY_FROM_VAR(&mtbbus_output_buf[3], rc_ll_diag.cutouts_data_ch2);
        break;

    case dvRCLLCutoutsNoReadyToParse:
        MEMCPY_FROM_VAR(&mtbbus_output_buf[3], rc_ll_diag.cutouts_no_ready_to_parse);
        break;

    case dvRCDCCPacketsReceived:
        MEMCPY_FROM_VAR(&mtbbus_output_buf[3], dcc_ll_diag.packets_received);
        break;

    case dvRCDCCBadXor:
        MEMCPY_FROM_VAR(&mtbbus_output_buf[3], dcc_ll_diag.bad_xor);
        break;

    case dvRCDCCLogical0PreambleSoon:
        MEMCPY_FROM_VAR(&mtbbus_output_buf[3], dcc_ll_diag.logical_0_preamble_soon);
        break;

    case dvRCDCCMobileDecodersRead:
        MEMCPY_FROM_VAR(&mtbbus_output_buf[3], dcc_mw_diag.mobile_reads);
        break;

    default:
        mtbbus_output_buf[0] = 2+0;
        mtbbus_warn_flags_old = mtbbus_warn_flags;
    }

    mtbbus_send_buf_autolen();
}

/* MTBbus speed autodetection ------------------------------------------------*/

void autodetect_mtbbus_speed(void) {
    gpio_pin_write(pin_led_blue, true);
    mtbbus_auto_speed_in_progress = true;
    mtbbus_auto_speed_last = MTBBUS_SPEED_38400;
    mtbbus_auto_speed_next();
}

void mtbbus_auto_speed_next(void) {
    mtbbus_auto_speed_timer = 0;
    mtbbus_auto_speed_last++; // relies on continuous interval of speeds
    if (mtbbus_auto_speed_last > MTBBUS_SPEED_MAX)
        mtbbus_auto_speed_last = MTBBUS_SPEED_38400;
    mtbbus_set_speed(mtbbus_auto_speed_last);
}

void mtbbus_auto_speed_received(void) {
    mtbbus_auto_speed_in_progress = false;
    config_mtbbus_speed = mtbbus_speed;
    config_write = true;
    gpio_pin_write(pin_led_blue, false);
}

void autodetect_mtbbus_speed_stop(void) {
    if (mtbbus_auto_speed_in_progress) {
        mtbbus_auto_speed_in_progress = false;
        gpio_pin_write(pin_led_blue, false);
    }
}

bool mtbbus_addressed(void) {
    return mtbbus_timeout < MTBBUS_TIMEOUT_MAX;
}

/* LEDs ----------------------------------------------------------------------*/

void leds_update(void) {
    if (led_gr_counter > 0) {
        led_gr_counter--;
        if (led_gr_counter == LED_GR_OFF)
            gpio_pin_write(pin_led_green, false);
    }

    bool led_red_flashing = error_flags.all;

    if (led_red_counter > 0) {
        led_red_counter--;
        if (((!led_red_flashing) && (led_red_counter == LED_RED_OK_OFF)) ||
            ((led_red_flashing) && (led_red_counter == LED_RED_ERR_OFF)))
            gpio_pin_write(pin_led_red, false);
    }
    if ((led_red_flashing) && (led_red_counter == 0)) {
        led_red_counter = LED_RED_ERR_ON;
        gpio_pin_write(pin_led_red, true);
    }

    if (led_blue_counter > 0) {
        led_blue_counter--;
        if (led_blue_counter == LED_BLUE_BEACON_OFF)
            gpio_pin_write(pin_led_blue, false);
    }
    if ((beacon) && (led_blue_counter == 0)) {
        led_blue_counter = LED_BLUE_BEACON_ON;
        gpio_pin_write(pin_led_blue, true);
    }
}

void led_red_ok(void) {
    if (led_red_counter == 0) {
        led_red_counter = LED_RED_OK_ON;
        gpio_pin_write(pin_led_red, true);
    }
}

/* Button --------------------------------------------------------------------*/

void btn_on_pressed(void) {
    btn_press_time = 0;
}

void btn_on_released(void) {
    if (btn_press_time < BTN_PRESS_1S)
        btn_short_press();
}

void btn_short_press(void) {
    if (mtbbus_auto_speed_in_progress) {
        autodetect_mtbbus_speed_stop();
        return;
    }

    uint8_t _mtbbus_addr = gpio_mtbbus_addr();
    error_flags.bits.addr_zero = (_mtbbus_addr == 0);
    mtbbus_addr = _mtbbus_addr;
    if (mtbbus_addr != 0)
        led_red_ok();
    mtbbus_update_polarity();
}

void btn_long_press(void) {
    if (!mtbbus_addressed())
        autodetect_mtbbus_speed();
}

///////////////////////////////////////////////////////////////////////////////

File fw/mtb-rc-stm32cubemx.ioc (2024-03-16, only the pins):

Mcu.UserName=STM32F103C8Tx
PA0-WKUP.GPIO_Label=DCC
PA0-WKUP.Signal=S_TIM2_CH1_ETR
PA1.GPIO_Label=MULT1
PA1.Signal=GPIO_Output
PA10.GPIO_Label=RC1_RX
PA10.Signal=USART1_RX
PA12.Signal=S_TIM1_ETR
PA13.Signal=SYS_JTMS-SWDIO
PA14.Signal=SYS_JTCK-SWCLK
PA2.Signal=USART2_TX
PA3.GPIO_Label=RC2_RX
PA3.Signal=USART2_RX
PA4.GPIO_Label=CUTOUT
PA4.Signal=GPXTI4
PA5.GPIO_Label=DEBUG1
PA5.Signal=GPIO_Output
PA6.GPIO_Label=DEBUG2
PA6.Signal=GPIO_Output
PA9.Signal=USART1_TX
PB0.GPIO_Label=ADDR1
PB0.Signal=GPIO_Input
PB1.GPIO_Label=ADDR2
PB1.Signal=GPIO_Input
PB10.GPIO_Label=MTB_TX
PB10.Signal=USART3_TX
PB11.GPIO_Label=MTB_RX
PB11.Signal=USART3_RX
PB12.GPIO_Label=LED_RED
PB12.Signal=GPIO_Output
PB13.GPIO_Label=LED_GREEN
PB13.Signal=GPIO_Output
PB14.GPIO_Label=LED_BLUE
PB14.Signal=GPIO_Output
PB15.GPIO_Label=BUTTON
PB15.Signal=GPIO_Input
PB2.GPIO_Label=ADDR4
PB2.Signal=GPIO_Input
PB3.GPIO_Label=ADDR8
PB3.Signal=GPIO_Input
PB4.GPIO_Label=ADDR16
PB4.Signal=GPIO_Input
PB5.GPIO_Label=ADDR32
PB5.Signal=GPIO_Input
PB6.GPIO_Label=ADDR64
PB6.Signal=GPIO_Input
PB7.GPIO_Label=ADDR128
PB7.Signal=GPIO_Input
PB9.GPIO_Label=MTB_TE
PB9.Signal=GPIO_Output
PD0-OSC_IN.Signal=RCC_OSC_IN
PD1-OSC_OUT.Signal=RCC_OSC_OUT

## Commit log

2023-03-20 zkouška
    vyzkoušení a seznámení s Kicad
    [komparator_kicad.kicad_pcb, komparator_kicad.kicad_sch]
2023-04-06 Add mooster schematics.
    [dcc.kicad_sch, mooster.kicad_pcb, mooster.kicad_sch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]
2023-07-11 mooster -> pcb, add fw directory.
    [dcc.kicad_sch, mooster.kicad_pcb, mooster.kicad_sch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]
2023-10-05 Move mooster to mooster directory.
    [dcc.kicad_sch, mooster.kicad_pcb, mooster.kicad_sch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]
2023-10-05 Add first shcematics.
    [dcc.kicad_sch, mtb.kicad_sch, railcomdet.kicad_pcb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]
2023-10-05 Wires adresses, add capacitors to MCU.
    [dcc.kicad_sch, mtb.kicad_sch, railcomdet.kicad_sch]
2023-10-05 Add power supply.
    [mtb.kicad_sch]
2023-10-05 Wire MTB bus driver.
    [mtb.kicad_sch]
2023-10-05 Finished MTB part.
    [dcc.kicad_sch, mtb.kicad_sch, railcomdet.kicad_sch]
2023-10-05 DCC WIP.
    [dcc.kicad_sch, mtb.kicad_sch]
2023-10-08 Some adjustments with comparators.
    [dcc.kicad_sch, komparator_kicad.kicad_pcb, komparator_kicad.kicad_sch]
2023-10-10 Updated DCC part.
    [dcc.kicad_sch]
2023-10-11 Some changes in dcc part.
    [dcc.kicad_sch]
2023-10-12 Added power stabilization in DCC.
    [dcc.kicad_sch]
2023-10-12 Finished DCC part.
    [dcc.kicad_sch]
2023-10-12 Connect DCC and MTB parts.
    [mtb.kicad_sch, railcomdet.kicad_sch]
2023-10-23 Added description.
    [dcc.kicad_sch, mtb.kicad_sch, railcomdet.kicad_sch]
2023-10-23 Added testpoints.
    [dcc.kicad_sch, mtb.kicad_sch, railcomdet.kicad_sch]
2023-10-23 Make ERC PASS.
    [dcc.kicad_sch, mtb.kicad_sch, railcomdet.kicad_sch]
2023-10-23 Added some footprints.
    [dcc.kicad_sch, mtb.kicad_sch, railcomdet.kicad_sch]
2023-10-28 Resistors added from 24.10.
    [mtb.kicad_sch]
2023-10-28 Added Sch.diodes, text editing..
    [dcc.kicad_sch, mtb.kicad_sch, railcomdet.kicad_sch]
2023-10-29 Edited resistors in MTB part.
    [mtb.kicad_sch]
2023-10-29 Resistors values edited in mtb part.
    [mtb.kicad_sch]
2023-10-29 eddited again.
    [mtb.kicad_sch]
2023-11-12 Added Schottky in DCC part and fuse footprint.
    [dcc.kicad_sch, mtb.kicad_sch]
2023-11-12 Added values schottky.
    [dcc.kicad_sch]
2023-11-14 Minor realign of new Schottkys.
    [dcc.kicad_sch]
2023-11-23 Remove mooster (outdated).
    [dcc.kicad_sch, mooster.kicad_pcb, mooster.kicad_sch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]
2023-11-23 root: rotate test points same way.
    [railcomdet.kicad_sch]
2023-11-23 Add several notes.
    [dcc.kicad_sch, mtb.kicad_sch, railcomdet.kicad_sch]
2023-11-23 Add rest of footprints.
    [dcc.kicad_sch, railcomdet.kicad_sch]
2023-11-23 Make TME attributes visible.
    [dcc.kicad_sch]
2023-12-07 Update note regarding diode thermal loss.
    [dcc.kicad_sch]
2023-12-07 PCB WIP.
    [dcc.kicad_sch, mtb.kicad_sch, railcomdet.kicad_pcb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]
2023-12-07 pcb: wire multiplexors.
    [dcc.kicad_sch, railcomdet.kicad_pcb]
2023-12-07 pcb: wire dcc voltage stabilization.
    [dcc.kicad_sch, railcomdet.kicad_pcb]
2023-12-09 pcb: wire multiplexer's inputs.
    [dcc.kicad_sch, mtb.kicad_sch, railcomdet.kicad_pcb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]
2023-12-09 Add filled zone to MTB part.
    [railcomdet.kicad_pcb]
2023-12-09 pcb: use THT testpins for DCC part.
    [railcomdet.kicad_pcb, railcomdet.kicad_sch]
2023-12-09 pcb: everything routed.
    [mtb.kicad_sch, railcomdet.kicad_pcb, railcomdet.kicad_sch]
2023-12-10 Use handsolder SMDs where possible.
    [dcc.kicad_sch, mtb.kicad_sch, railcomdet.kicad_pcb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]
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2023-12-10 Use SOT83-handsolder for DCC part.
    [dcc.kicad_sch, railcomdet.kicad_pcb]
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2023-12-10 Wire empty inputs of U11.
    [dcc.kicad_sch, railcomdet.kicad_pcb]
2023-12-10 Use smaller pull-ups for RailCom RX.
    [railcomdet.kicad_sch]
2023-12-10 Tweak optocoupler LED current.
    [railcomdet.kicad_sch]
2023-12-10 VEE of 4052 to -5VA.
    [dcc.kicad_sch, railcomdet.kicad_pcb]
2023-12-10 Use MAX478 as a MTBbus driver.
    [mtb.kicad_sch, railcomdet.kicad_pcb]
2023-12-11 Use double J & K connectors.
    [railcomdet.kicad_pcb, railcomdet.kicad_sch]
2023-12-11 78L05 -> 78M05. AMS1113-3.3 -> HT7533.
    [mtb.kicad_sch, railcomdet.kicad_pcb]
2023-12-11 Add RS485 level shifting.
    [mtb.kicad_sch, railcomdet.kicad_pcb]
2023-12-11 Resolve some DRC issues.
    [railcomdet.kicad_pcb]
2023-12-12 MTB: couple 3V3 stabilizer serially with 5V stabilizer.
    [mtb.kicad_sch, railcomdet.kicad_pcb]
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2023-12-13 Resolve DRC issues.
    [mtb-rc.kicad_pcb]
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2023-12-14 More space for STlink connector.
    [mtb-rc.kicad_pcb]
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2023-12-17 Cleanup tracks & vias.
    [mtb-rc.kicad_pcb]
2023-12-17 Remove unused pads & vias.
    [mtb-rc.kicad_pcb]
2023-12-17 Run DRC, add exclusions.
    [mtb-rc.kicad_pcb]
2023-12-26 Use 2×MVE252-5-V footprint.
    To avoid DRC issues in PCB.
    [mtb-rc.kicad_pcb, mtb-rc.kicad_sch]
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2023-12-30 Shortly turn on LEDs at startup.
    [main.c]
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2024-01-02 Use 4×MVE252-5-V footprint.
    To avoid DRC issues in schematics.
    [mtb-rc.kicad_pcb, mtb-rc.kicad_sch]
2024-01-12 R40: fix orientation.
    [mtb.kicad_sch]
2024-01-13 Add optocoupler-led protection diode. Close #1.
    [mtb-rc.kicad_pcb, mtb-rc.kicad_sch, mtb.kicad_sch]
2024-01-13 Remove "PAD" value of testpads where pads are not used.
    [mtb-rc.kicad_pcb, mtb-rc.kicad_sch]
2024-01-14 Use 12 MHz oscillator, internal freq=48 MHz.
    [main.c, mtb-rc-stm32cubemx.ioc]
2024-01-16 Use 12MHz oscillator.
    [mtb.kicad_sch]
2024-01-20 Use THT electrolytic capacitors for DCC stabilization.
    22uF/25V tantalum capacitors are too big.
    [dcc.kicad_sch, mtb-rc.kicad_pcb]
2024-03-09 Use most local assert instead of return values.
    So the error could be distinguished at the most-specific level (__FILE__, __LINE__).
    [main.c, mtbbus.c, railcom.c]
2024-03-09 Fix RX/TX/TE silkscreen positions.
    [dcc.kicad_sch, mtb-rc.kicad_pcb, mtb-rc.kicad_sch]
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2024-03-16 Fix silly bug :).
    [railcom_ll.c]
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2024-04-27 dcc_ll: resolve SWexla mismatch.
    [dcc_ll.c]
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2024-05-18 R28 1k -> 4k7 (LED).
    [dcc.kicad_sch, mtb-rc.kicad_pcb]
2024-05-23 Sch: slightly move wires.
    [dcc.kicad_sch]
2024-05-23 Add REF+/- capacitors C30, C31, C32, C33.
    These capacitors filter out any disturbances in REF+ & REF- signals.
    [dcc.kicad_sch, mtb-rc.kicad_pcb]
2024-05-23 Change REF to 10 mV.
    This allows a decoder in 3 parallery connected track circuits to be
    safely detected (e.g. a loco shorts neighbour track circuits).
    [dcc.kicad_sch, mtb-rc.kicad_pcb]
2024-07-21 Bootloader: call 'fail' on unknown interrupt.
    [main.c]
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2024-08-01 Bootloader: make mtb addr reading work.
    I don't know why it didn't work before.
    [gpio.c]
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2024-08-01 Bootloader: fix typos, add speed mockup.
    [main.c]

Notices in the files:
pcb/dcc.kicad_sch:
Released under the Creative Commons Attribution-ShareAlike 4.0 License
